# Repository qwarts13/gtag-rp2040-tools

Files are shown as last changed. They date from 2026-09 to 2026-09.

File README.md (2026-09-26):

# G-Tag RP2040 Tools

Два измерительных прибора на одной плате **RP2040-Zero** с экраном от
электронного ценника **G-Tag (SES-imagotag)** 256×128.

| Инструмент | Что делает |
|---|---|
| **Тестер USB-портов** | щуп втыкается в порт ПК: измеряет VBUS, реальные уровни D+ и D−, сопротивление линий, находит замыкания и опознаёт зарядное устройство |
| **Тестер инициализации ПК** | USB-C втыкается в тестируемый компьютер: пассивно, без единого нажатия клавиши, измеряет шкалу загрузки — когда прошивка подняла USB и когда управление забрала операционная система |

Обе функции живут в одной прошивке
[`firmware/GTag_Tester`](firmware/GTag_Tester) и переключаются сами.

**Как выбирается режим.** Прибор постоянно следит за хостом. Перечислил нас
компьютер — по кабелю идут данные, значит включается тестер инициализации.
Хоста нет — значит это зарядка, работает тестер портов. Проверка идёт
непрерывно и не сдаётся: если машина поднимет USB только через несколько
минут, прибор дождётся и начнёт отсчёт с этого момента.

Кнопка **BOOT**: короткое нажатие переворачивает картинку в режиме портов и
перезапускает замер в режиме инициализации, долгое — переключает режим
вручную. Ручной выбор держится до переподключения кабеля, дальше снова
работает автоматика.

---

## Как это выглядит

Экран тестера портов:

```
1 VBUS              4.77V
2 D-                0.02V 25K
3 D+                0.02V 25K
4 GND              USB ТЕСТЕР
```

Экран тестера инициализации:

```
        ТЕСТЕР ИНИЦИАЛИЗАЦИИ ПК
┌──────────────────────────────────┐
│  INIT                YES         │
└──────────────────────────────────┘
┌──────────────────────────────────┐
│  OS BOOT            27.4S        │
└──────────────────────────────────┘
```

Схемы подключения: [распиновка](images/pinout.svg) ·
[щуп с делителем](images/probe.svg) · [подключение экрана](images/lcd.svg).

Живые снимки: [тестер портов на столе](images/photos/running-port.jpg) ·
[замер живого порта](images/photos/measuring-live-port.jpg) ·
[режим инициализации](images/photos/running-init.jpg) ·
[внутренности сборки](images/photos/inside.jpg) ·
[в корпусе](images/photos/case-closed.jpg).

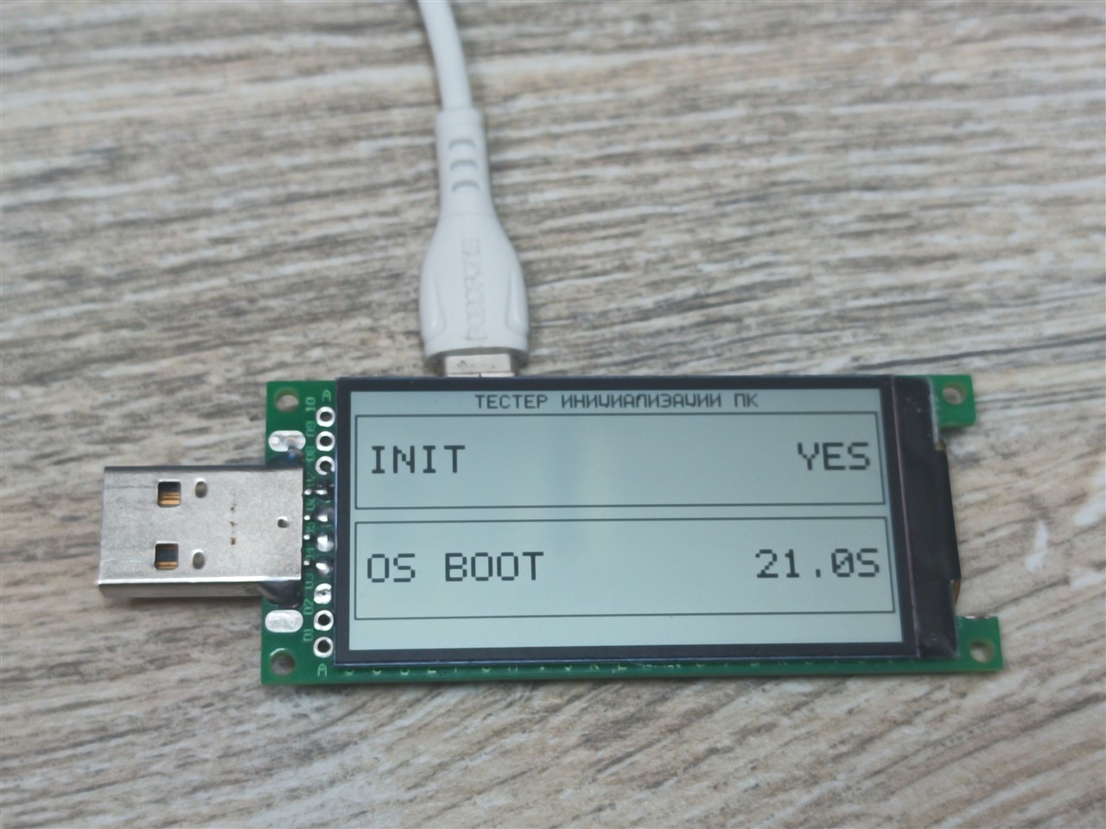
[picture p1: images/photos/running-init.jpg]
Тестер инициализации ПК


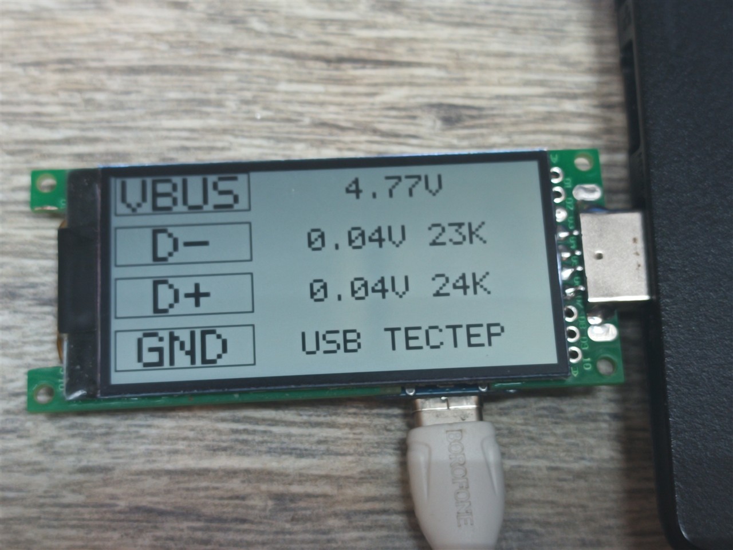
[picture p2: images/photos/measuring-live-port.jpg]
Тестер портов измеряет живой порт


---

## Железо

| Что | Зачем |
|---|---|
| RP2040-Zero | мозг, USB-контроллер и АЦП |
| Экран от ценника G-Tag 256×128 | индикатор, четыре сигнальных провода |
| Плата ценника (остаётся в сборе) | питание экрана и **DisplayCLK 28,8 кГц** |
| USB-A штекер на проводах | измерительный щуп тестера портов |
| Динамик | сигнал о замыкании и о подтверждённой инициализации |

Всё это собрано на **макетной плате 3×7 см**: на ней разместились RP2040-Zero,
обвязка щупа (делитель 100к/100к, резисторы 1к, эталон 10к) и динамик. Экран
вынесен на четырёх проводах, плата ценника остаётся в своём корпусе и даёт
`DisplayCLK`.

### Распиновка RP2040-Zero (USB-C сверху)

```
        левый край                 правый край
        5V        (1)              (23)  GP0
        GND       (2)              (22)  GP1
        3V3       (3)              (21)  GP2
        GP29      (4)              (20)  GP3
        GP28      (5)              (19)  GP4
        GP27      (6)              (18)  GP5
        GP26      (7)              (17)  GP6
        GP15      (8)              (16)  GP7
        GP14      (9)              (15)  GP8
              нижний торец:  GP13(10) GP12(11) GP11(12) GP10(13) GP9(14)
```

### Подключение

| Сигнал | GPIO |
|---|---|
| Экран: RESET / CS / CLK / DIO | GP8 / GP9 / GP10 / GP11 |
| Экран: GND | GND |
| Щуп: VBUS через делитель 100к/100к | GP26 |
| Щуп: D− через 1к | GP27 |
| Щуп: D+ через 1к | GP28 |
| Эталонный резистор 10к на GND | GP29 |
| Динамик | GP7 |

Подробности, включая защиту линий данных и проверку мультиметром перед
первым включением — в [docs/wiring.md](docs/wiring.md).

Как снять экран со штатного ценника и что там перерезать — в
[docs/tag-preparation.md](docs/tag-preparation.md).

## Корпус

Печатный корпус под эту сборку лежит в [hardware/stl](hardware/stl) — три
STL-файла, печать на FDM, стягивается четырьмя винтами. Внутри помещаются
RP2040-Zero, обвязка щупа и динамик; USB-C и кнопка BOOT выведены наружу,
щуп выходит слева.

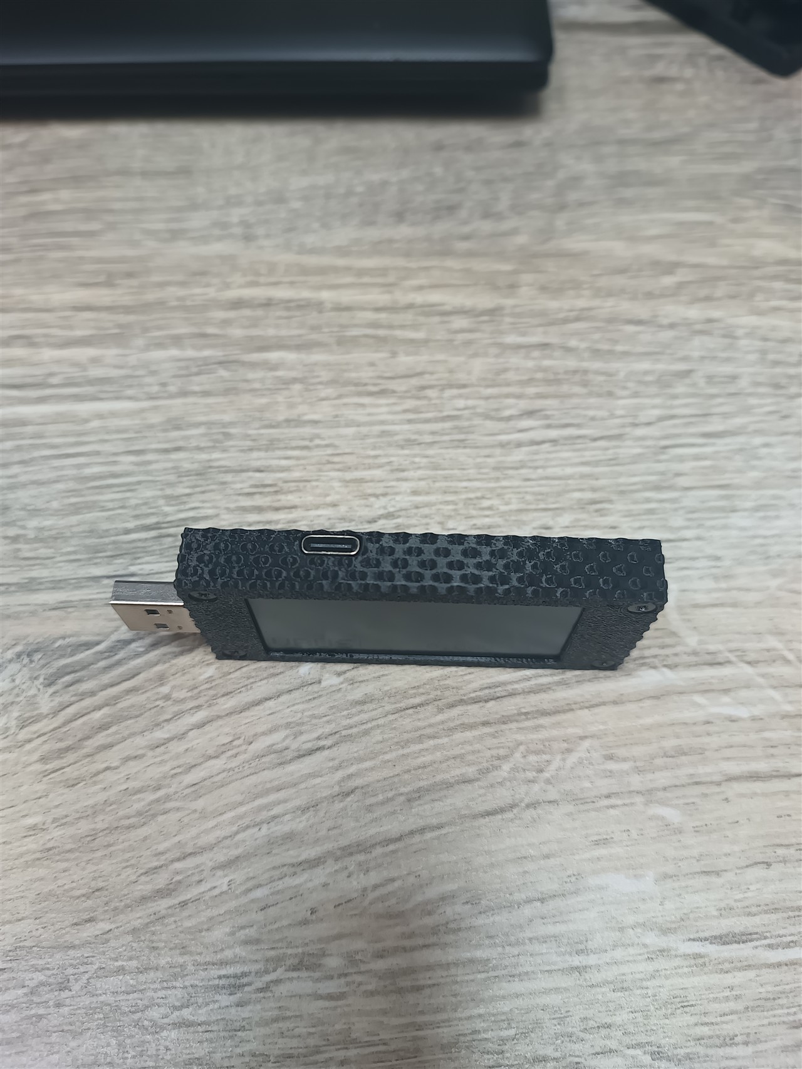
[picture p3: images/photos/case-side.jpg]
Корпус, вид сбоку


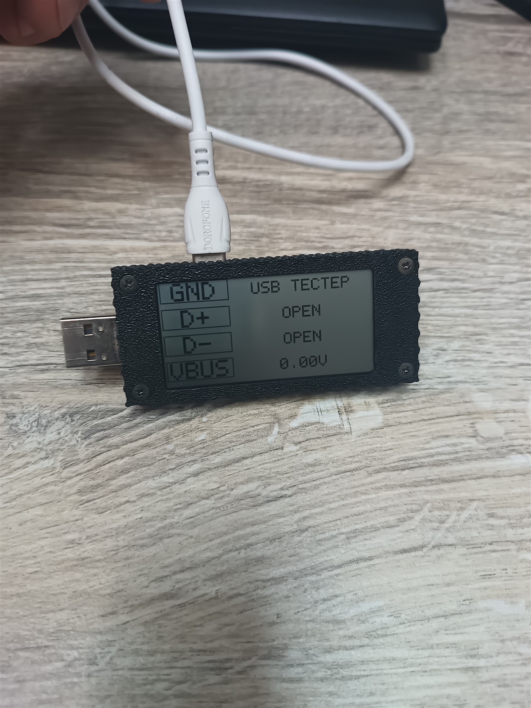
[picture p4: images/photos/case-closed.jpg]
Собранный прибор


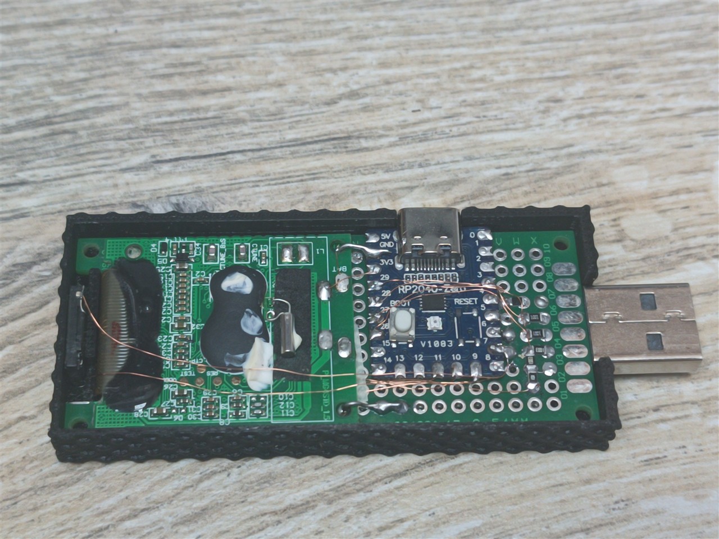
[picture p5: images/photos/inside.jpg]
Сборка изнутри


---

## Быстрая прошивка готовым файлом

Собирать самому не обязательно. Готовый бинарник живёт **только в релизах** —
в дереве репозитория его нет намеренно, чтобы ни у кого случайно не оказалось
старой версии. Прямая ссылка всегда отдаёт последнюю:

```
https://github.com/qwarts13/gtag-rp2040-tools/releases/latest/download/GTag_Tester.uf2
```

Затем:

1. Зажать **BOOT** на плате и подключить USB-C — появится диск `RPI-RP2`.
2. Перетащить на него `GTag_Tester.uf2`.
3. Плата сама перезагрузится и запустится.

Собрано под `Waveshare RP2040 Zero` со стеком Adafruit TinyUSB. Формат UF2
привязан к семейству чипа, а не к конкретной модели платы, поэтому файл
подойдёт любому RP2040.

## Сборка из исходников

Скетч для **Arduino IDE 2.x** с ядром
[Raspberry Pi Pico/RP2040 by Earle Philhower](https://github.com/earlephilhower/arduino-pico).

1. **File → Preferences → Additional boards manager URLs:**
   `https://github.com/earlephilhower/arduino-pico/releases/download/global/package_rp2040_index.json`
2. **Tools → Boards → Boards Manager** → установить *Raspberry Pi Pico/RP2040*.
3. **Tools → Board** → `Waveshare RP2040 Zero`.
4. **Tools → USB Stack → Adafruit TinyUSB.** Это обязательно: тестер
   инициализации представляется HID-клавиатурой, а без TinyUSB сборка
   останавливается с ошибкой «TinyUSB is not selected».
5. Открыть `firmware/GTag_Tester/GTag_Tester.ino`, залить. Первая заливка —
   с зажатой кнопкой BOOT (плата определится как диск `RPI-RP2`).

---

## Тестер USB-портов

Щуп идёт в порт под тестом, питание — от зарядки, вставленной в USB-C.

Для каждой линии измеряется реальное напряжение, классифицируется состояние
сети и оценивается сопротивление до земли:

| Состояние | Что означает |
|---|---|
| `OPEN` | линия ни к чему не подключена |
| `HOST PULL-DOWN` | видны подтяжки хоста 15к — порт живой |
| `DEVICE PULL-UP` | линию держит вверху подключённое устройство |
| `SHORT TO GND` | линию не поднять, она на земле |

КЗ между D+ и D− ищется так: одна линия подтягивается вверх, вторая вниз, и
если они «съезжают» вместе — значит замкнуты. На экране между строками
появляется двусторонняя стрелка, а динамик пищит.

Зарядное устройство опознаётся по подписи BC1.2: у него D+ и D− соединены
накоротко, поэтому обе линии высокие и одинаковые. Это тоже считается
замыканием и тоже озвучивается — тестер не делает скидок на то, что так
задумано производителем.

### Как измеряется сопротивление

Сопротивление считается по внутренней подтяжке RP2040, а её номинал плавает
в диапазоне 40–80к. Поэтому при старте прошивка калибруется по двум известным
резисторам на плате: эталонному 10к на GP29 и нижнему плечу делителя 100к на
GP26. Из двух уравнений находятся сразу оба неизвестных — сопротивление
подтяжки и реальное напряжение её шины.

Проверка на живом примере: 15к, припаянные к линии вместо щупа, показываются
как 16к — с учётом последовательного резистора 1к. Подробности в
[docs/calibration.md](docs/calibration.md).

---

## Тестер инициализации ПК

USB-C идёт в компьютер под тестом, устройство представляется HID-клавиатурой.
Дальше **не нажимается ни одна клавиша** — тестер только слушает то, что хост
делает сам.

| Метка | Событие |
|---|---|
| `INIT` | хост перечислил устройство. Это и есть инициализация порта, и она фиксируется независимо от того, прошивка это или ОС |
| `OS BOOT` | время от инициализации до того, как дала о себе знать ОС: либо сброс шины и повторное перечисление, либо состояние лампочек клавиатуры, которое присылает драйвер |

### Почему без нажатий

Нажатие клавиши даёт ответ только если хост уже обрабатывает клавиатуру:
BIOS, поднявший порт, но не загрузивший драйвер ввода, промолчит. Поэтому
тестер слушает только то, что хост делает сам:

- **перечисление устройства** — присвоение USB-адреса и конфигурация;
- **трафик на шине** — хост опрашивает нас постоянно, пока жив;
- **состояние лампочек** (`SET_REPORT`, выходной отчёт) — Windows и Linux
  присылают его при загрузке драйвера, без единого нажатия;
- **смена протокола boot → report** — признак того, что управление забрала ОС.

Кнопка BOOT: короткое нажатие — перезапуск замера, долгое — переключение
режима прибора.

---

## Что внутри экрана

Протокол LCD восстановлен не на глаз: последовательность команд, формат
9-битных слов и тайминги сверены с записью логического анализатора, снятой с
штатной прошивки ценника в проекте
[**lukdut/gtag-nrf-display**](https://github.com/lukdut/gtag-nrf-display)
(лицензия MIT). Драйвер LCD в этом репозитории — его порт на RP2040.
Инициализация отправляет ровно 4172 слова, кадр — 4100, и это совпадает
байт в байт. Разбор — в [docs/lcd-protocol.md](docs/lcd-protocol.md).

Огромная благодарность автору того проекта: без снятого захвата пришлось бы
разбирать протокол вслепую.

---

## Автор

Евгений Кузьмин ([@Qwarts13](https://github.com/Qwarts13)).

## Лицензия

MIT, см. [LICENSE](LICENSE).

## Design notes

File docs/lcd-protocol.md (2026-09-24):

# Протокол экрана G-Tag

Драйвер не написан на глаз: последовательность команд, формат слов и тайминги
сверены с записью логического анализатора, снятой с **штатной прошивки
ценника** в проекте
[lukdut/gtag-nrf-display](https://github.com/lukdut/gtag-nrf-display), файл
`docs/lcd-protocol-review.md`.

## Интерфейс

От платы к экрану идут **четыре сигнала**:

| Сигнал | GPIO |
|---|---|
| RESET | GP8 |
| CS | GP9 |
| CLK | GP10 |
| DIO | GP11 |

`DisplayCLK` (~28,8 кГц) и питание экрана даёт сама плата ценника. Прошивка
этот сигнал не формирует. `TE` в этой модели не используется.

## Передача слова

Каждое слово — **9 бит**: первый бит признак «команда или данные», затем восемь
бит данных, старшим вперёд.

```
CLK в покое низкий
CS опускается
устанавливается бит D/C
данные выставляются при низком CLK
CLK поднимается — данные защёлкиваются
... и так девять раз
CS поднимается после КАЖДОГО слова
```

Полупериод CLK — около 2 мкс, то есть примерно 250 кГц. Чтобы было понятно,
насколько это «медленно» и надёжно: у записанного оригинала период гулял в
пределах 3,5–4,25 мкс, так что мы укладываемся в тот же коридор.

## Последовательность инициализации

| Этап | Слова | Пауза после |
|---|---|---|
| `11` — выход из сна, затем очистка всех 16 страниц по 256 байт значением `FF` | 4161 | 10 мс |
| `4C 0C 00 00 00` — именно **четыре** байта данных | 5 | 4 мс |
| `4D FF 00 7F` | 4 | 1 мс |
| `4E 60` | 2 | 500 мс |
| **итого** | **4172** | |

## Вывод кадра

```
2A 00 00   — адрес 0
2C         — запись в память
4096 байт  — сам кадр
```

Итого 4100 слов.

## Формат кадра

Кадр — 4096 байт, по биту на пиксель.

```
индекс байта = y * 32 + x / 8
бит          = x % 8
значение 1   = белый
```

Разрешение 256×128.

Счётчик слов — независимая проверка: он не зависит от того, как выглядит
картинка. В нашей реализации он выводит в Serial:

```
init total   779 ms   4172 words  exp 4172 OK
frame        210 ms   4100 words  exp 4100 OK
```

Значит в панель уходит ровно тот же поток слов, что и у штатной прошивки
ценника, вплоть до количества.

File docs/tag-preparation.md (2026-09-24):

# Подготовка платы ценника

Экран, который мы используем, снят со штатного электронного ценника G-Tag.
Штатная плата ценника при этом **остаётся в сборке и работает**: именно она
питает LCD и выдаёт тактирование `DisplayCLK / S1` на 28,8 кГц. Прошивка
RP2040 этот сигнал не формирует.

Наша задача — перерезать четыре дорожки, отделив линии управления LCD от
штатного контроллера ценника, и вывести эти четыре сигнала наружу.

> **Не путать:** `CLK` в таблице ниже — это тактовая линия передачи данных,
> отдельный провод. `DisplayCLK / S1` — другой сигнал, его трогать не нужно,
> он так и остаётся на плате ценника.

## Порядок работы

### 1. Открыть корпус

Поддеть защёлки отвёрткой и вынуть сборку платы с экраном.

### 2. Отклеить плату от экрана

Плата держится на двустороннем скотче. Аккуратно поддеть край и прикладывать
небольшое постоянное усилие — скотч постепенно отпустит. Не тянуть резко и не
натягивать шлейф.

### 3. Перерезать четыре дорожки

Очистить обратную сторону платы от остатков скотча (механически или спиртом)
и дать высохнуть. Перерезать дорожки **в четырёх местах**, отмеченных красными
штрихами на фото:

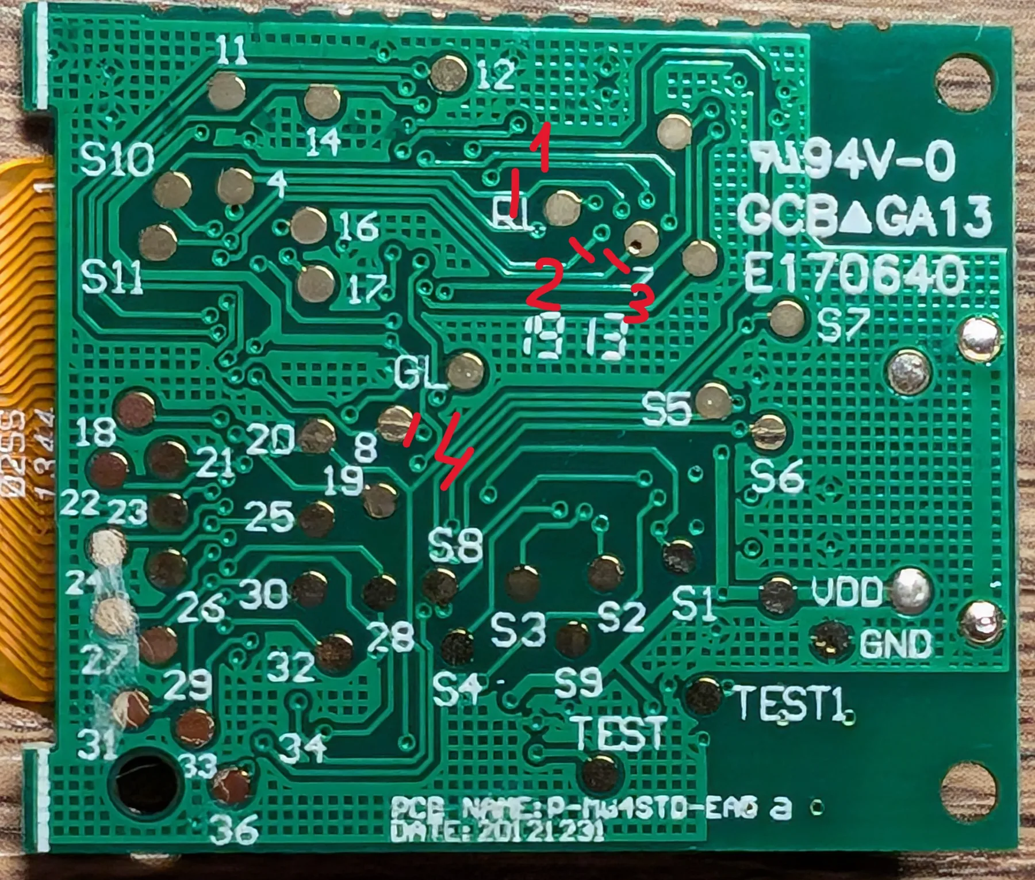
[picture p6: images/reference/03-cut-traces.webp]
Четыре места разрезания дорожек на обратной стороне платы


После работы обязательно проверить мультиметром, что каждый разрез
действительно разрывает нужную дорожку, а соседние остались целыми.

### 4. Подготовить точки пайки

Найти четыре точки **DIO, CLK, CS и RESET**, залудить их:

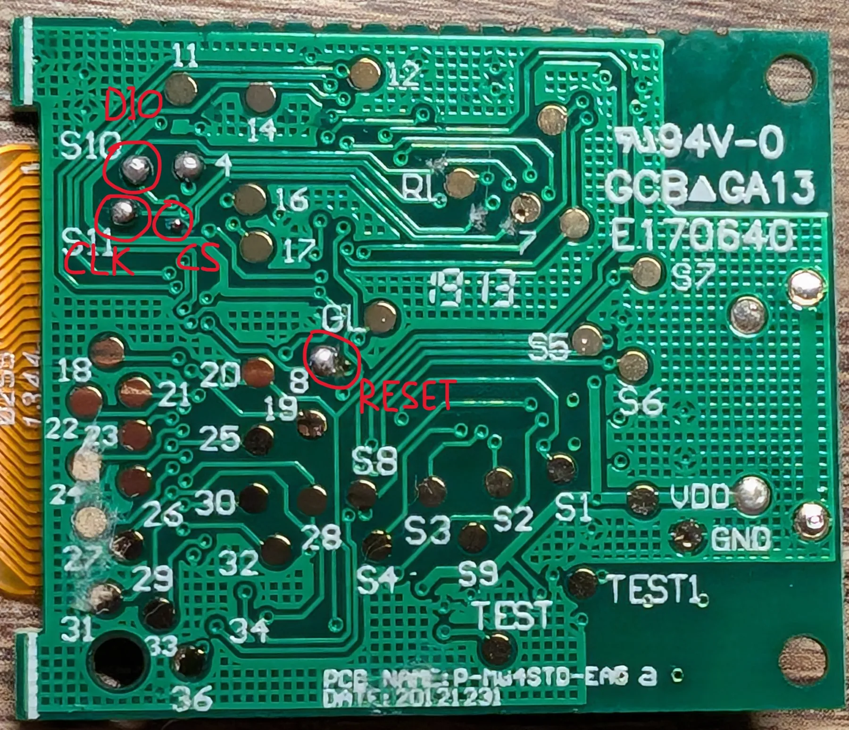
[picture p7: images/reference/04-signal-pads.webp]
Подписанные точки пайки DIO, CLK, CS и RESET


### 5. Припаять провода

Уложить четыре сигнальных провода вдоль поверхности платы, чтобы они не
торчали перпендикулярно. Питание вывести двумя проводами: плюс и минус.

## Куда что идёт на RP2040

| Провод от экрана | GPIO на RP2040-Zero | Пин на плате |
|---|---|---|
| RESET | GP8 | 15 |
| CS | GP9 | 14 |
| CLK | GP10 | 13 |
| DIO | GP11 | 12 |
| GND | GND | 2 |

Плюс обязательная общая земля между RP2040 и платой ценника.

## Источник

Фотографии и порядок операций взяты из проекта
[lukdut/gtag-nrf-display](https://github.com/lukdut/gtag-nrf-display), раздел
`docs/display-preparation.md` (лицензия MIT). Там же описан вариант разводки,
когда переходное отверстие находится рядом с контрольной площадкой, а не на
ней — на некоторых ревизиях платы разрез делается иначе.

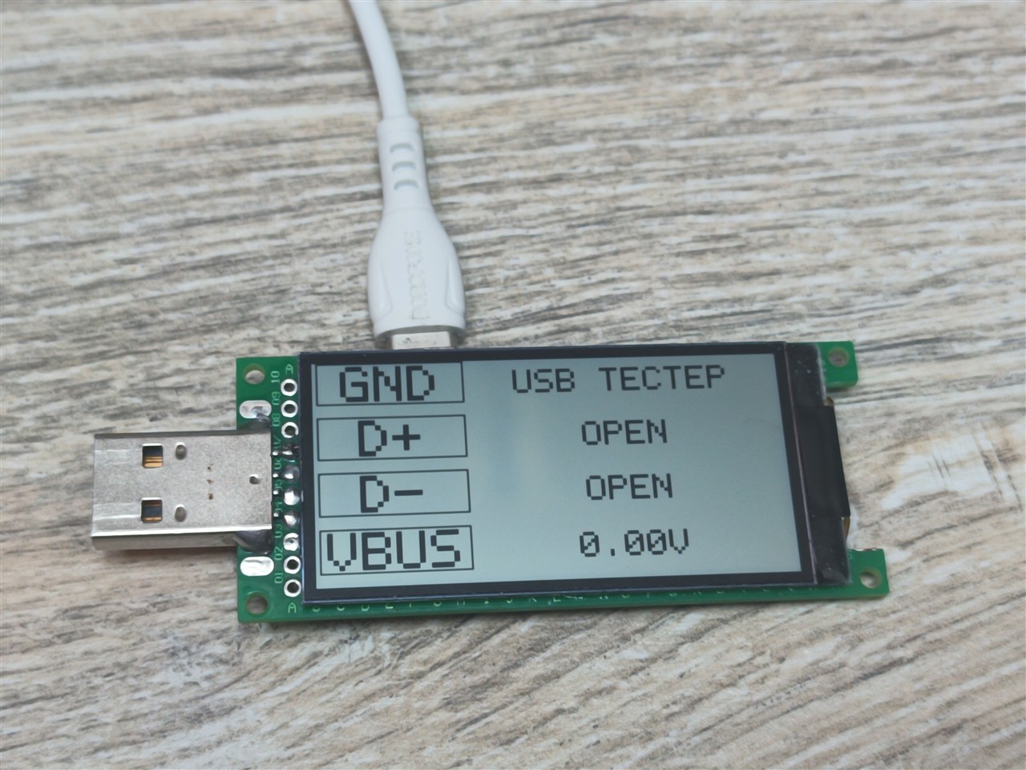
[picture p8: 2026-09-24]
images/photos/running-port.jpg

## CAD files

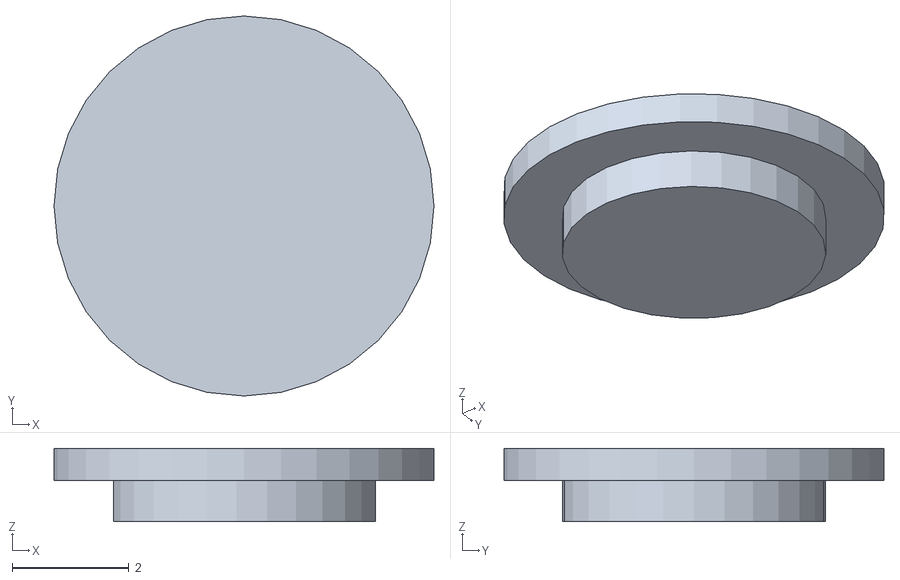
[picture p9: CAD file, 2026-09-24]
hardware/stl/USB_Tester_3.stl
6.50 x 6.50 x 1.25

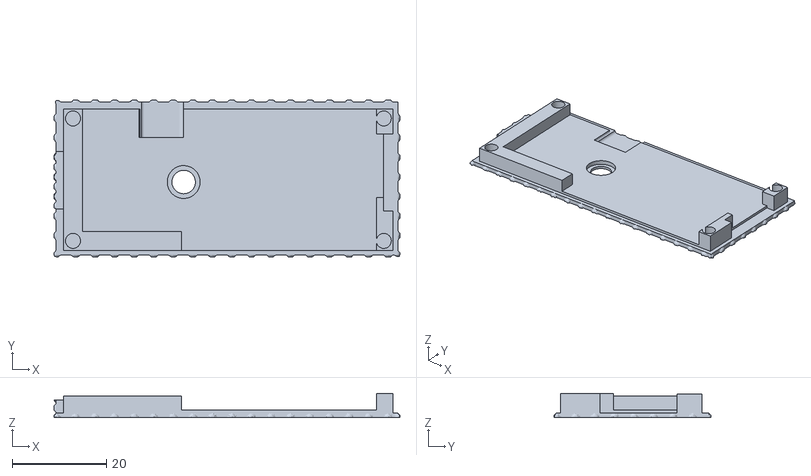
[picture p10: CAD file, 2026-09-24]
hardware/stl/USB_Tester_2.stl
73.5 x 33.4 x 5.20

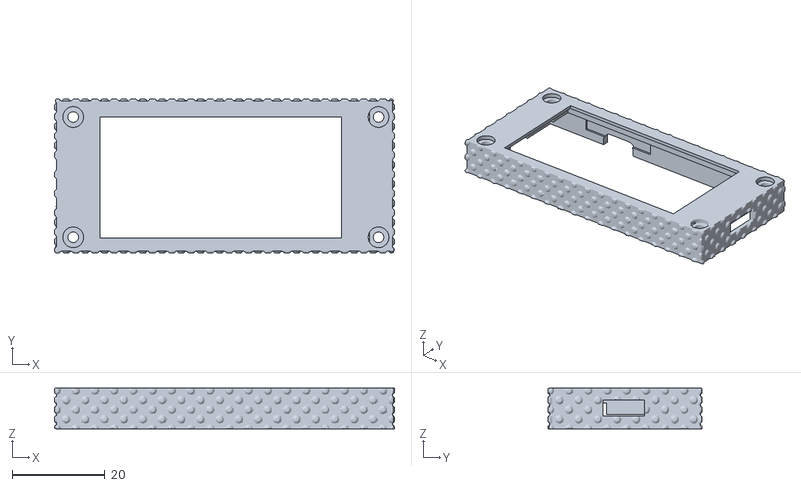
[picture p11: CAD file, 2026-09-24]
hardware/stl/USB_Tester_1.stl
73.5 x 33.4 x 8.80

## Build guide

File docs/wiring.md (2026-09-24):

# Подключение

## Состав устройства

1. **RP2040-Zero** — мозг, USB-контроллер, АЦП.
2. **Экран от ценника G-Tag** 256×128 — индикатор.
3. **Плата ценника** — остаётся в сборе. Именно она питает экран и выдаёт
   `DisplayCLK` 28,8 кГц. Без неё картинки не будет.
4. **USB-A штекер на проводах** — измерительный щуп тестера портов.
5. **Динамик** — сигнал о замыкании и о подтверждённой инициализации.

Родной USB-C платы не трогаем: он остаётся для питания и для режима
HID-клавиатуры.

## Распиновка RP2040-Zero

Нумерация — позиции площадок, при **USB-C сверху**. На шелкографии платы
подписаны имена GPIO, так что ориентируйся по ним.

```
        левый край                 правый край
        5V        (1)              (23)  GP0
        GND       (2)              (22)  GP1
        3V3       (3)              (21)  GP2
        GP29      (4)              (20)  GP3
        GP28      (5)              (19)  GP4
        GP27      (6)              (18)  GP5
        GP26      (7)              (17)  GP6
        GP15      (8)              (16)  GP7
        GP14      (9)              (15)  GP8
              нижний торец:  GP13(10) GP12(11) GP11(12) GP10(13) GP9(14)

        пин 2 = GND, пин 3 = 3V3, пин 1 = 5V, пин 23 = VSYS (= VUSB)
```

## Экран от ценника

| Сигнал экрана | GPIO | Пин на плате |
|---|---|---|
| RESET | GP8 | 15 |
| CS | GP9 | 14 |
| CLK | GP10 | 13 |
| DIO | GP11 | 12 |
| GND | GND | 2 |

**Не подключаем:**

- `XCLK` / `DisplayCLK` — его выдаёт штатная плата ценника. Прошивка этот
  сигнал не формирует.
- `TE` — в этом экране не используется вообще.

Плата ценника обязана остаться подключённой: она питает LCD и даёт
`DisplayCLK`. В проекте
[lukdut/gtag-nrf-display](https://github.com/lukdut/gtag-nrf-display) для этого
на обратной стороне платы ценника перерезают четыре дорожки, отделяя линии
управления LCD от штатного контроллера, и выводят их наружу — раздел
`display-preparation` в их репозитории.

Провода экрана держать короткими, общий GND — как можно короче.

## Щуп

Берём USB-A штекер и четыре провода. Нумерация контактов USB-A стандартная:
1 = VBUS, 2 = D−, 3 = D+, 4 = GND.

| USB-A | Линия | Куда на плате | Через что |
|---|---|---|---|
| 1 | VBUS | GP26 (пин 7) | делитель 100к + 100к |
| 2 | D− | GP27 (пин 6) | резистор 1к |
| 3 | D+ | GP28 (пин 5) | резистор 1к |
| 4 | GND | GND (пин 2) | напрямую |

### Делитель VBUS

Здесь чаще всего путаются, поэтому подробно. Нужны **два одинаковых резистора
по 100к**, включённых последовательно, а провод на GP26 берётся **из точки
между ними**:

```
   USB-A VBUS (контакт 1) ────[ 100к ]
                                   │
                                   ├──── GP26 (пин 7)   ← средняя точка
                                   │
                              [ 100к ]
                                   │
   USB-A GND (контакт 4) ──────────┴──── GND платы
```

Резисторы равны, поэтому 5 В делятся ровно пополам: на GP26 приходит 2,5 В.
Это безопасно для АЦП.

**Главное:** провод на GP26 идёт в середину цепочки. Если припаять его к
краю — к самому VBUS или к земле — делить будет нечего, и напряжение мерить
будет нечем.

### Почему именно АЦП-пины

У RP2040 аналоговый вход есть **только** на GP26…GP29. На обычных цифровых
пинах `analogRead` вернёт ноль, и тестер не сможет измерить ни напряжение,
ни сопротивление. Поэтому щуп обязан стоять именно на этих четырёх ногах.

Зато видно не «0 или 1», а реальное напряжение, и состояние линии
определяется однозначно:

```
0 В на обоих          — устройство не подключено
~3,0–3,3 В на D+      — подключено full-speed устройство
~3,0–3,3 В на D−      — подключено low-speed устройство
одинаково на обоих    — замыкание D+ на D−
~0 В при подтяжке     — КЗ на GND
```

### Защита

Между линиями данных и GPIO **обязателен резистор 1к**, а лучше ещё и
диодная сборка.

В режиме поиска неисправностей на линии может оказаться 5 В, а GPIO RP2040
больше 3,6 В не терпят. Резистор ограничивает ток, сборка **BAT54S** зажимает
напряжение на безопасном уровне.

BAT54S (SOT-23), цоколёвка: вывод 1 — анод нижнего диода, вывод 2 — катод
верхнего, вывод 3 — середина. Подключение на каждую линию данных:

```
   USB-A D+ ──[ 1к ]──┬─── GP28
                      │
                   ┌──┴──┐
                   │  3  │   BAT54S
                  1│     │2
                   │     │
                  GND   3V3
```

Нужно **две** такие сборки — по одной на D+ и D−.

Если BAT54S не найти, подойдут четыре обычных диода Шоттки, по два на линию:
один от линии на 3V3 (катодом к 3V3), второй с GND на линию (катодом к
линии). Подойдут 1N5817, 1N5819, BAT85.

**Важно:** нужен именно **Шоттки**. Обычный кремниевый диод откроется только
при 3,3 + 0,7 = 4,0 В, а это уже выше предела для GPIO.

## Эталонный резистор

```
   GP29 (пин 4) ──[ 10к ]── GND
```

Сопротивления на линиях данных считаются по внутренней подтяжке RP2040, а её
номинал плавает в диапазоне 40–80к. Этот резистор служит эталоном: при старте
прошивка измеряет через него свою подтяжку и дальше считает точно. Без него
числа будут приблизительными.

## Динамик

| Тип динамика | Подключение | Настройка |
|---|---|---|
| Пассивный пьезо | GP7 → пьезо → GND | `BUZZER_ACTIVE 0` |
| Активный буззер | плюс на GP7, минус на GND | `BUZZER_ACTIVE 1` |
| Магнитный (с катушкой) | через резистор ~100 Ом, диод параллельно | `BUZZER_ACTIVE 0` |

## Питание

Питаем устройство **от родного USB-C**.

Если запитать тестер портов от порта компьютера, прибор увидит перечисление
USB, примет это за данные и запустится в режиме тестера инициализации. Это не
ошибка — по шине действительно идут данные. Лечится зарядкой либо долгим
нажатием кнопки.

**Внимание по RP2040-Zero:** пин 23 (VSYS) напрямую соединён с VUSB, то есть
с VBUS родного разъёма. Нельзя одновременно втыкать USB-C и подавать 5 В со
щупа на пин 23 — получится два источника на одной цепи.

## Проверка мультиметром перед первым включением

1. GND платы ↔ GND USB-A: звонятся, ~0 Ом
2. USB-A VBUS ↔ GP26: ~200к
3. GP26 ↔ GND: ~100к
4. D− ↔ GP27: ~1к
5. D+ ↔ GP28: ~1к
6. GP29 ↔ GND: ~10к
7. VBUS ↔ GND: низкого сопротивления быть НЕ должно
8. D+ ↔ D−: низкого сопротивления быть НЕ должно

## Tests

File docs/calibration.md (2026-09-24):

# Калибровка измерений

## Задача

Тестер показывает не только напряжение, но и сопротивление линий данных.
Измерять его напрямую нечем — в схеме нет ни образцового резистора на линии,
ни источника тока. Единственный доступный инструмент — **внутренняя подтяжка
RP2040**: если подать её на измеряемую линию, по установившемуся напряжению
можно восстановить внешнее сопротивление.

```
   R = Rpullup * V / (Vcc - V)
```

Беда в том, что `Rpullup` у RP2040 не нормирован точно: паспорт даёт разброс
примерно 40–80к, и у каждой платы он свой. Плюс АЦП не идеален. Если взять
паспортные 50к и ровно 3,3 В, ошибка выходит в разы.

## Решение: два известных резистора

На плате уже есть **два резистора с известным номиналом**, и оба висят на
АЦП-пинах:

| Резистор | Пин | Номинал |
|---|---|---|
| эталонный | GP29 | 10к на землю |
| нижнее плечо делителя VBUS | GP26 | 100к на землю |

Это даёт **две точки** и, соответственно, два уравнения — значит можно найти
сразу **два** неизвестных: сопротивление подтяжки и реальное напряжение её
шины.

Измеряем напряжение на каждом из них при включённой подтяжке:

```
v10  = Vcc * 10  / (Rpu + 10)
v100 = Vcc * 100 / (Rpu + 100)
```

Делим одно на другое и решаем систему:

```
Rpu = 54900 Ом
Vcc = 3.95 В
```

Полученные значения подставляются в формулу сопротивления. Прошивка делает
это сама при старте и печатает результат в Serial:

```
cal: Rpu=59682 ohm  Vcc=4.053 V  (v10=0.596 v1=2.950 vbus=4.78)
```

## Про получившееся «Vcc = 4 В»

Шина подтяжки питается от 3,3 В, там физически не может быть четырёх вольт.
Это не ошибка расчёта, а следствие того, что АЦП и внутренняя подтяжка не
подчиняются простой модели «резистор к питанию»: подгонка выкручивает
параметр, чтобы попасть в две известные точки.

Практический смысл в том, что **в диапазоне между этими двумя точками
результат получается верным**: модель, подогнанная по 10к и 100к, честно
считает и промежуточные номиналы вокруг 15–25к, то есть именно тот диапазон,
который встречается на линиях USB.

## Проверка

Живой тест: вместо щупа на линию D− припаивается резистор **15к**, и тестер
показывает **16к** — ровно 15к плюс последовательный 1к в линии.

На другом порту тестер показал 24к вместо ожидаемых 16к. Ошибки здесь нет:
у того порта действительно другие подтяжки.

## Когда калиброваться

Лучше всего — при **воткнутом щупе в живой порт** или **вообще без щупа**.
Прошивка различает три случая по состоянию линии VBUS:

| `vbus` | Ситуация | Что видит GP26 |
|---|---|---|
| > 0,3 В | щуп в живом порту | верхнее плечо сидит на VBUS, ветка учитывается |
| < 0,03 В | щуп в мёртвом порту | оба плеча грузят пин |
| между | щуп не воткнут | только нижнее плечо 100к |

Во всех трёх случаях система решается корректно.

## Точность

| Что | Насколько точно |
|---|---|
| Напряжение VBUS | делитель работает по соотношению, оно верное при любых одинаковых резисторах |
| Классификация линий (пусто / хост / устройство / КЗ) | надёжна, пороги разнесены широко |
| Абсолютное сопротивление | точное в диапазоне 10к–100к при откалиброванной подтяжке |
| Сопротивление вне этого диапазона | оценочное |

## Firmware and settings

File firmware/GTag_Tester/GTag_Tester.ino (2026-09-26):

// ============================================================
//  GTag_Tester - one board, two instruments
//
//  1. USB PORT TESTER - probe in the port under test, measures VBUS, D+ and
//     D- voltages, line resistance, shorts, charger signatures. Powered from
//     a charger (no data on the USB-C connector).
//
//  2. PC INIT TESTER - the USB-C goes into the machine under test. The board
//     enumerates as a USB HID keyboard and, without pressing anything,
//     watches what the host does by itself: enumeration, keyboard LED state,
//     protocol handover, re-enumeration.
//
//  Mode selection:
//    - at power up the board waits a few seconds. If the host enumerated us
//      there is data on the connector, so it starts the init tester,
//      otherwise it assumes a charger and starts the port tester.
//    - BOOTSEL short press: flip the picture (port tester) / restart the
//      measurement (init tester).
//    - BOOTSEL long press: switch mode manually.
//
//  IMPORTANT: Tools -> USB Stack must be set to "Adafruit TinyUSB".
//
//  Board: RP2040-Zero, core: Raspberry Pi Pico/RP2040 (Earle Philhower)
//    LCD    -> GP8..GP11, plus the tag board for DisplayCLK
//    Buzzer -> GP7, optional
//    Probe  -> GP26 VBUS (100k/100k), GP27 D-, GP28 D+, GP29 10k reference
// ============================================================

#include <Arduino.h>
#include "Adafruit_TinyUSB.h"
#include "gtag_lcd.h"

// ---------------- config ----------------
#define PIN_BUZZER       7
#define BUZZER_ACTIVE    0            // 0 = passive piezo (tone), 1 = active buzzer
static constexpr uint16_t BEEP_HZ = 2200;

#define PIN_VBUS    26   // ADC0, through 100k/100k divider
#define PIN_DPLUS   28   // ADC2
#define PIN_DMINUS  27   // ADC1
#define REF_PIN     29   // ADC3, 10k to GND
#define REF_OHM     10000
#define PULLUP_NOMINAL 50000.0f

static constexpr float    VCC      = 3.3f;
static constexpr bool     INK      = false;   // black ink on white paper
static constexpr float    SHORT_V  = 0.5f;    // cross-line coupling threshold
static constexpr uint32_t DRAW_MS  = 400;
static constexpr uint32_t LOG_MS   = 1500;
static constexpr uint32_t PRESS_LONG_MS = 700;  // longer than this = mode switch

static float g_pullup = PULLUP_NOMINAL;   // refined by calibration
static float g_vcc    = VCC;

// ---------------- measurement types ----------------
// Must sit before the first function: the Arduino builder inserts the
// generated prototypes just ahead of the first function body.
enum LineState : uint8_t { LN_UNKNOWN, LN_OPEN, LN_HOST_PD, LN_DEV_UP, LN_SHORT_GND };

struct Reading {
  float     vbus;
  float     vP, vN;
  float     rP, rN;
  float     rShort;
  LineState sP, sN;
  bool      shortPN;
  uint16_t  actP, actN;
};

enum Mode : uint8_t { MODE_PORT, MODE_INIT };

// ---------------- HID ----------------
static uint8_t const desc_hid_report[] = { TUD_HID_REPORT_DESC_KEYBOARD() };
Adafruit_USBD_HID usb_hid;

static void hid_report_callback(uint8_t report_id, hid_report_type_t report_type,
                                uint8_t const *buffer, uint16_t bufsize);

static volatile uint32_t led_reports = 0;
static volatile uint8_t  led_state   = 0;

// The host's keyboard LED state arrives here. No key press is involved: the
// OS and the Linux kernel send this on their own when the driver loads.
static void hid_report_callback(uint8_t report_id, hid_report_type_t report_type,
                                uint8_t const *buffer, uint16_t bufsize) {
  (void)report_id;
  if (report_type != HID_REPORT_TYPE_OUTPUT || bufsize < 1) return;
  led_state = buffer[0];
  ++led_reports;
}

// ---------------- buzzer ----------------
static void buzzer_set(bool on) {
#if BUZZER_ACTIVE
  digitalWrite(PIN_BUZZER, on ? HIGH : LOW);
#else
  if (on) tone(PIN_BUZZER, BEEP_HZ);
  else    noTone(PIN_BUZZER);
#endif
}

static void buzzer_beep(int times, uint16_t ms) {
  for (int i = 0; i < times; ++i) {
    buzzer_set(true);  delay(ms);
    buzzer_set(false); delay(ms);
  }
}

static void beep_joy() {
#if BUZZER_ACTIVE
  buzzer_set(true); delay(300); buzzer_set(false);
#else
  tone(PIN_BUZZER, 1600); delay(120); noTone(PIN_BUZZER); delay(60);
  tone(PIN_BUZZER, 2400); delay(220); noTone(PIN_BUZZER);
#endif
}

static void buzzer_alarm(bool alarm) {
  static uint32_t last = 0;
  static bool phase = false;
  if (!alarm) {
    if (phase) { buzzer_set(false); phase = false; }
    return;
  }
  const uint32_t now = millis();
  if ((uint32_t)(now - last) >= 120) {
    last = now;
    phase = !phase;
    buzzer_set(phase);
  }
}

// ============================================================
//  Port tester: measurement
// ============================================================
static float adc_volts(uint8_t pin) {
  uint32_t acc = 0;
  for (int i = 0; i < 8; ++i) acc += (uint32_t)analogRead(pin);
  return (acc / 8.0f) * VCC / 4096.0f;
}

static uint16_t count_edges(uint8_t pin, uint32_t us) {
  gpio_set_function(pin, GPIO_FUNC_SIO);
  gpio_set_dir(pin, GPIO_IN);
  gpio_set_input_enabled(pin, true);

  const uint32_t t0 = micros();
  uint16_t edges = 0;
  int last = gpio_get(pin) ? 1 : 0;
  while ((uint32_t)(micros() - t0) < us) {
    const int v = gpio_get(pin) ? 1 : 0;
    if (v != last) { ++edges; last = v; }
  }

  gpio_set_input_enabled(pin, false);
  gpio_set_function(pin, GPIO_FUNC_NULL);
  return edges;
}

static float r_to_gnd(float v) {
  if (v >= VCC - 0.15f) return -1.0f;
  if (v <= 0.02f)       return 0.0f;
  return g_pullup * v / (g_vcc - v);
}

static float r_between(float v) {
  if (v < 0.1f) return -1.0f;
  const float r = g_pullup * (g_vcc / v - 2.0f);
  return (r < 0.0f) ? 0.0f : r;
}

// The pull-up test decides the state; a line that collapses under a pull-down
// was never really held high.
static LineState classify(float base_v, float pullup_v, float pulldown_v) {
  if (base_v >= 2.5f) {
    return (pulldown_v >= 2.0f) ? LN_DEV_UP : LN_OPEN;
  }
  if (pullup_v >= VCC - 0.3f) return LN_OPEN;
  if (pullup_v >= 0.35f)      return LN_HOST_PD;
  return LN_SHORT_GND;
}

static Reading measure_port() {
  Reading r{};

  gpio_set_pulls(PIN_VBUS, false, false);
  r.vbus = adc_volts(PIN_VBUS) * 2.0f;           // undo the divider

  gpio_set_pulls(PIN_DPLUS, false, false);
  gpio_set_pulls(PIN_DMINUS, false, false);
  delayMicroseconds(300);
  r.vP = adc_volts(PIN_DPLUS);
  r.vN = adc_volts(PIN_DMINUS);

  gpio_set_pulls(PIN_DPLUS, true, false);        // raise D+, hold D- down
  gpio_set_pulls(PIN_DMINUS, false, true);
  delayMicroseconds(300);
  const float uP = adc_volts(PIN_DPLUS);
  const float nUp = adc_volts(PIN_DMINUS);

  gpio_set_pulls(PIN_DPLUS, false, true);        // raise D-, hold D+ down
  gpio_set_pulls(PIN_DMINUS, true, false);
  delayMicroseconds(300);
  const float uN = adc_volts(PIN_DMINUS);
  const float pUp = adc_volts(PIN_DPLUS);

  gpio_set_pulls(PIN_DPLUS, false, false);
  gpio_set_pulls(PIN_DMINUS, false, false);

  // Smoothing keeps the display from flickering, which matters most when the
  // probe is unplugged and the lines are floating.
  static bool  have = false;
  static float sP = 0, sN = 0, sUp = 0, sUn = 0, sBus = 0, sPdn = 0, sNdn = 0;
  if (!have) {
    sP = r.vP; sN = r.vN; sUp = uP; sUn = uN; sBus = r.vbus;
    sPdn = pUp; sNdn = nUp;
    have = true;
  } else {
    const float a = 0.7f;
    sP   = sP   * a + r.vP  * (1.0f - a);
    sN   = sN   * a + r.vN  * (1.0f - a);
    sUp  = sUp  * a + uP    * (1.0f - a);
    sUn  = sUn  * a + uN    * (1.0f - a);
    sBus = sBus * a + r.vbus * (1.0f - a);
    sPdn = sPdn * a + pUp   * (1.0f - a);
    sNdn = sNdn * a + nUp   * (1.0f - a);
  }
  r.vP = sP; r.vN = sN; r.vbus = sBus;
  r.sP = classify(sP, sUp, sPdn);
  r.sN = classify(sN, sUn, sNdn);
  r.rP = r_to_gnd(sUp);
  r.rN = r_to_gnd(sUn);

  const float coupling = (nUp > pUp) ? nUp : pUp;
  r.shortPN = coupling > SHORT_V;
  r.rShort = r.shortPN ? r_between(coupling) : -1.0f;

  r.actP = count_edges(PIN_DPLUS, 5000);
  r.actN = count_edges(PIN_DMINUS, 5000);
  return r;
}

// Two known resistors let us solve for the pull-up value and the effective
// pull-up rail at once: the 10k reference on GP29 and the 100k lower divider
// leg on GP26.
static void calibrate() {
#if REF_OHM > 0
  analogRead(REF_PIN);
  analogRead(PIN_VBUS);

  gpio_set_pulls(REF_PIN, true, false);
  delayMicroseconds(500);
  const float v10 = adc_volts(REF_PIN);
  gpio_set_pulls(REF_PIN, false, false);

  gpio_set_pulls(PIN_VBUS, false, false);
  delayMicroseconds(500);
  const float v0 = adc_volts(PIN_VBUS);

  gpio_set_pulls(PIN_VBUS, true, false);
  delayMicroseconds(500);
  const float v1 = adc_volts(PIN_VBUS);
  gpio_set_pulls(PIN_VBUS, false, false);

  const float vbus = v0 * 2.0f;

  if (v10 > 0.05f) {
    float vcc = g_vcc;
    if (v0 > 0.3f) {
      const float den = 10.0f * v10 - 2.0f * v1 + vbus;   // live VBUS branch
      if (den > 0.1f) vcc = v10 * (8.0f * v1 + vbus) / den;
    } else if (v0 < 0.03f) {
      const float den = 5.0f * v10 - v1;                  // VBUS grounded
      if (den > 0.1f) vcc = 4.0f * v1 * v10 / den;
    } else {
      const float den = 10.0f * v10 - v1;                 // probe unplugged
      if (den > 0.1f) vcc = 9.0f * v1 * v10 / den;
    }
    if (vcc > 2.5f && vcc < 4.6f) {
      const float rpu = (vcc - v10) * (float)REF_OHM / v10;
      if (rpu > 8000.0f && rpu < 200000.0f) g_pullup = rpu;
      g_vcc = vcc;
    }
  }

  Serial.printf("cal: Rpu=%.0f ohm  Vcc=%.3f V  (v10=%.3f v1=%.3f vbus=%.2f)\n",
                g_pullup, g_vcc, v10, v1, vbus);
#else
  (void)REF_PIN;
  Serial.printf("pull-up assumed: %.0f ohm\n", g_pullup);
#endif
}

static const char *state_name(LineState s) {
  switch (s) {
    case LN_OPEN:      return "OPEN";
    case LN_HOST_PD:   return "HOST PULL-DOWN";
    case LN_DEV_UP:    return "DEVICE PULL-UP";
    case LN_SHORT_GND: return "SHORT TO GND";
    default:           return "UNKNOWN";
  }
}

static void fmt_ohm(char *buf, size_t n, float r) {
  if (r < 0.0f || r >= 1000000.0f) snprintf(buf, n, "OPEN");
  else if (r < 1000.0f)            snprintf(buf, n, "%.0f", r);
  else                             snprintf(buf, n, "%.0fK", r / 1000.0f);
}

static void verdict_text(const Reading &r, char *l1, size_t n1, char *l2, size_t n2) {
  l1[0] = l2[0] = 0;
  if (r.vbus < 1.0f) {
    snprintf(l1, n1, "НЕТ ПИТАНИЯ НА VBUS");
    snprintf(l2, n2, "ПРОВЕРЬ КАБЕЛЬ И ПОРТ");
  } else if (r.shortPN) {
    snprintf(l1, n1, "ЗАМЫКАНИЕ D+ И D-");
    snprintf(l2, n2, "ПРОВЕРЬ ПОРТ И КАБЕЛЬ");
  } else if (r.sP == LN_DEV_UP) {
    snprintf(l1, n1, "УСТРОЙСТВО ПОДКЛЮЧЕНО");
    snprintf(l2, n2, "СКОРОСТЬ ВЫСОКАЯ");
  } else if (r.sN == LN_DEV_UP) {
    snprintf(l1, n1, "УСТРОЙСТВО ПОДКЛЮЧЕНО");
    snprintf(l2, n2, "СКОРОСТЬ НИЗКАЯ");
  } else if (r.sP == LN_HOST_PD || r.sN == LN_HOST_PD) {
    snprintf(l1, n1, "ПОРТ ИСПРАВЕН");
    snprintf(l2, n2, "УСТРОЙСТВ НЕ НАЙДЕНО");
  } else if (r.sP == LN_OPEN && r.sN == LN_OPEN) {
    snprintf(l1, n1, "ЛИНИИ ДАННЫХ ОТКРЫТЫ");
    snprintf(l2, n2, "ПОРТ ПУСТ ИЛИ МЕРТВ");
  } else {
    snprintf(l1, n1, "ПРОВЕРЬ ЛИНИИ");
    snprintf(l2, n2, "СМОТРИ СОСТОЯНИЕ");
  }
}

// Both lines held high at once is not a valid USB state for a device: it
// happens when the two lines are tied together, which a charger does on
// purpose and a faulty port does by accident.
static bool both_lines_high(const Reading &r) {
  return r.sP == LN_DEV_UP && r.sN == LN_DEV_UP;
}

static bool looks_like_rail_short(const Reading &r) {
  return both_lines_high(r) && r.vP >= 3.0f && r.vN >= 3.0f;
}

static void print_reading(const Reading &r) {
  char rbP[10], rbN[10], rbS[10], l1[28], l2[28];
  fmt_ohm(rbP, sizeof(rbP), r.rP);
  fmt_ohm(rbN, sizeof(rbN), r.rN);
  fmt_ohm(rbS, sizeof(rbS), r.rShort);
  verdict_text(r, l1, sizeof(l1), l2, sizeof(l2));
  Serial.printf("VBUS %.2f V | D+ %.2f V (%s, R %s) | D- %.2f V (%s, R %s)\n",
                r.vbus, r.vP, state_name(r.sP), rbP, r.vN, state_name(r.sN), rbN);
  Serial.printf("short D+/D-: %s (R %s) | activity D+ %u  D- %u\n",
                r.shortPN ? "YES" : "no", rbS, r.actP, r.actN);
  Serial.printf("verdict: %s / %s\n", l1, l2);
  if (looks_like_rail_short(r))
    Serial.println("WARNING: both lines at the rail - suspect D+/D- shorted to +5V");
  else if (both_lines_high(r))
    Serial.println("short: D+ and D- are tied together (charger signature or faulty port)");
}

// ---------------- port tester screen ----------------
static void render_port(const Reading &r) {
  char rbP[10], rbN[10];
  fmt_ohm(rbP, sizeof(rbP), r.rP);
  fmt_ohm(rbN, sizeof(rbN), r.rN);

  memset(glcd_fb, 0xFF, sizeof(glcd_fb));

  static const char *const label[4] = {"VBUS", "D-", "D+", "GND"};
  char val[4][20];

  if (r.vbus < 0.5f) snprintf(val[0], sizeof(val[0]), "0.00V");
  else               snprintf(val[0], sizeof(val[0]), "%.2fV", r.vbus);

  if (r.sN == LN_OPEN)     snprintf(val[1], sizeof(val[1]), "OPEN");
  else if (r.shortPN)      snprintf(val[1], sizeof(val[1]), "%.2fV SHORT", r.vN);
  else if (r.rN >= 0)      snprintf(val[1], sizeof(val[1]), "%.2fV %s", r.vN, rbN);
  else                     snprintf(val[1], sizeof(val[1]), "%.2fV", r.vN);

  if (r.sP == LN_OPEN)     snprintf(val[2], sizeof(val[2]), "OPEN");
  else if (r.shortPN)      snprintf(val[2], sizeof(val[2]), "%.2fV SHORT", r.vP);
  else if (r.rP >= 0)      snprintf(val[2], sizeof(val[2]), "%.2fV %s", r.vP, rbP);
  else                     snprintf(val[2], sizeof(val[2]), "%.2fV", r.vP);

  snprintf(val[3], sizeof(val[3]), "USB ТЕСТЕР");

  const int scaleL = 3, scaleV = 2;
  const int boxX = 2, boxW = 80;
  const int ry[4] = {2, 34, 66, 98};
  // The rotated view lists GND first, the plain view lists VBUS first.
  static const int orderRot[4]  = {3, 2, 1, 0};
  static const int orderFlat[4] = {0, 1, 2, 3};
  const int *ord = glcd_flip ? orderRot : orderFlat;

  int idxDm = -1, idxDp = -1, idxGnd = -1;
  for (int i = 0; i < 4; ++i) {
    if (ord[i] == 1) idxDm = i;
    if (ord[i] == 2) idxDp = i;
    if (ord[i] == 3) idxGnd = i;
  }

  for (int i = 0; i < 4; ++i) {
    const int k = ord[i], yy = ry[i];
    rect(boxX, yy - 2, boxW, 25);
    const int tw = textChars(label[k]) * 6 * scaleL;
    drawText(boxX + (boxW - tw) / 2, yy, label[k], scaleL);
    drawTextCenter(169, yy + 4, val[k], scaleV);
  }

  if (r.shortPN && idxDm >= 0 && idxDp >= 0) {
    drawVArrow(244, ry[idxDm] + 10, ry[idxDp] + 10);
  } else {
    if (r.sP == LN_SHORT_GND && idxDp >= 0 && idxGnd >= 0)
      drawVArrow(244, ry[idxDp] + 10, ry[idxGnd] + 10);
    if (r.sN == LN_SHORT_GND && idxDm >= 0 && idxGnd >= 0)
      drawVArrow(236, ry[idxDm] + 10, ry[idxGnd] + 10);
  }
}

// ============================================================
//  Init tester: passive boot milestones
// ============================================================
static uint32_t it_t0    = 0;   // first enumeration
static uint32_t it_led   = 0;   // first LED state from the host
static uint32_t it_os    = 0;   // protocol handover or re-enumeration
static bool     it_os_seen = false;
static bool     it_saw_boot = false;
static bool     it_beeped   = false;

static void init_test_reset() {
  it_t0 = it_led = it_os = 0;
  led_reports = 0;
  led_state = 0;
  it_os_seen = false;
  it_saw_boot = false;
  it_beeped = false;
  if (TinyUSBDevice.mounted()) it_t0 = millis();
}

static void fmt_time(char *b, size_t n, uint32_t mark) {
  if (mark == 0 || it_t0 == 0 || mark < it_t0) { snprintf(b, n, "--"); return; }
  snprintf(b, n, "%.1fS", (mark - it_t0) / 1000.0f);
}

static void render_init() {
  memset(glcd_fb, 0xFF, sizeof(glcd_fb));

  drawTextCenter(GLCD_W / 2, 2, "ТЕСТЕР ИНИЦИАЛИЗАЦИИ ПК", 1);

  // The OS is detected by whichever host signal shows up first.
  uint32_t t_load = 0;
  if (it_os && it_led) t_load = (it_os < it_led) ? it_os : it_led;
  else                 t_load = it_os ? it_os : it_led;

  char v1[20], v2[20];
  snprintf(v1, sizeof(v1), "%s", (it_t0 != 0) ? "YES" : "NO");
  fmt_time(v2, sizeof(v2), t_load);

  static const char *const label[2] = {"INIT", "OS BOOT"};
  const char *val[2] = {v1, v2};
  const int boxY[2] = {12, 66};

  for (int i = 0; i < 2; ++i) {
    rect(2, boxY[i], 252, 48);
    drawText(8, boxY[i] + 16, label[i], 2);
    drawTextRight(250, boxY[i] + 16, val[i], 2);
  }
}

// ============================================================
//  Sketch
// ============================================================
static Mode     g_mode   = MODE_PORT;
static bool     g_manual = false;   // the user has chosen a mode by hand

// 0 = nothing, 1 = short press, 2 = long press. BOOTSEL reads the flash CS
// pad, so only sample it on demand.
static uint8_t button_event() {
  static bool     down = false;
  static uint32_t tDown = 0;
  static bool     longSent = false;
  static uint32_t lastSample = 0;

  const uint32_t ms = millis();
  // Reading BOOTSEL floats the flash chip select and disables interrupts for
  // a moment, so sample it at 50 Hz and not in a tight spin.
  if ((uint32_t)(ms - lastSample) < 20) return 0;
  lastSample = ms;

  const bool now = BOOTSEL;
  uint8_t ev = 0;

  if (now && !down) {
    down = true;
    tDown = millis();
    longSent = false;
  } else if (now && down && !longSent &&
             (uint32_t)(millis() - tDown) >= PRESS_LONG_MS) {
    longSent = true;
    ev = 2;
  } else if (!now && down) {
    down = false;
    if (!longSent && (uint32_t)(millis() - tDown) >= 40) ev = 1;   // ignore bounce
  }
  return ev;
}

static void switch_mode() {
  g_mode = (g_mode == MODE_PORT) ? MODE_INIT : MODE_PORT;
  g_manual = true;
  if (g_mode == MODE_INIT) init_test_reset();
  else                     buzzer_beep(1, 80);
  Serial.printf("mode: %s (manual until replug)\n",
                (g_mode == MODE_INIT) ? "init tester" : "port tester");
}
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
void loop() {
  const uint32_t now = millis();

  // ---- follow the host, forever ----
  // An enumerated host means we are on a computer, so this is the init tester.
  // No host at all means a charger, so this is the port tester. The check runs
  // on every pass and never gives up: a machine that only brings its USB up
  // after several minutes is still caught, and the timeline starts at that
  // moment. Replugging clears any manual choice.
  static bool prevMounted = false;
  const bool mounted = TinyUSBDevice.mounted();
  if (mounted != prevMounted) {
    g_manual = false;
    if (mounted) {
      if (it_t0 == 0) {
        it_t0 = now;
        if (!it_beeped) { it_beeped = true; beep_joy(); }
        Serial.println("INIT   enumerated");
      } else if (!it_os_seen) {
        it_os_seen = true;
        it_os = now;
        Serial.printf("OS     re-enumerated   %.1f s\n", (it_os - it_t0) / 1000.0f);
      }
    }
    prevMounted = mounted;
  }

  const Mode autoMode = mounted ? MODE_INIT : MODE_PORT;
  if (!g_manual && g_mode != autoMode) {
    g_mode = autoMode;
    Serial.printf("mode: %s (auto)\n",
                  (g_mode == MODE_INIT) ? "init tester" : "port tester");
  }

  // ---- host-driven milestones, no key presses anywhere ----
  if (it_t0 != 0 && it_led == 0 && led_reports > 0) {
    it_led = now;
    Serial.printf("LED    host set lamps  %.1f s\n", (it_led - it_t0) / 1000.0f);
  }

  const bool reportProto = (usb_hid.getProtocol() == HID_PROTOCOL_REPORT);
  if (!reportProto) it_saw_boot = true;
  if (it_saw_boot && reportProto && it_t0 != 0 && !it_os_seen) {
    it_os_seen = true;
    it_os = now;
    Serial.printf("OS     report protocol %.1f s\n", (it_os - it_t0) / 1000.0f);
  }

  // ---- one button, two gestures ----
  const uint8_t ev = button_event();
  if (ev == 2) {
    switch_mode();
  } else if (ev == 1) {
    if (g_mode == MODE_PORT) {
      glcd_flip = !glcd_flip;                     // turn the picture around
      Serial.printf("flip=%d\n", glcd_flip ? 1 : 0);
    } else {
      init_test_reset();                          // start the measurement over
      Serial.println("init measurement restarted");
    }
  }

  if (g_mode == MODE_PORT) {
    // ---- port tester ----
    static uint32_t tDraw = 0;
    if ((uint32_t)(now - tDraw) >= DRAW_MS) {
      tDraw = now;
      const Reading r = measure_port();
      render_port(r);
      lcd_send_frame(glcd_fb);
      buzzer_alarm(r.shortPN || r.sP == LN_SHORT_GND || r.sN == LN_SHORT_GND ||
                   both_lines_high(r));
      static uint8_t tick = 0;
      if (++tick >= 5) { tick = 0; print_reading(r); }
    }
  } else {
    // ---- init tester: only the screen here, milestones are handled above ----
    static uint32_t tDraw = 0;
    if ((uint32_t)(now - tDraw) >= DRAW_MS) {
      tDraw = now;
      render_init();
      lcd_send_frame(glcd_fb);
    }
  }

  static uint32_t tLog = 0;
  if ((uint32_t)(now - tLog) >= LOG_MS) {
    tLog = now;
    Serial.printf("mode=%s host=%s proto=%s led=%s reports=%lu\n",
                  (g_mode == MODE_INIT) ? "init" : "port",
                  TinyUSBDevice.mounted() ? "up" : "down",
                  (usb_hid.getProtocol() == HID_PROTOCOL_REPORT) ? "report" : "boot",
                  (led_state & KEYBOARD_LED_NUMLOCK) ? "numlock-on" : "numlock-off",
                  (unsigned long)led_reports);
  }
}

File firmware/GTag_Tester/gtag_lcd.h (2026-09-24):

// ============================================================
//  gtag_lcd.h - G-Tag 256x128 LCD driver, 4-wire transport + 5x7 font
//
//  Shared by the G-Tag tools. Transport verified word for word against a
//  logic-analyzer capture of the stock firmware (see the
//  lukdut/gtag-nrf-display project, docs/lcd-protocol-review.md).
//
//  Default wiring, change the four defines below if you moved the wires:
//    DIO=GP11  CLK=GP10  CS=GP9  RESET=GP8
//  DisplayCLK (~28.8 kHz) is supplied by the tag board and is not driven here.
//
//  Framebuffer: byte index y*32 + x/8, bit x%8, 1 = white.
// ============================================================
#pragma once
#include <Arduino.h>

#define LCD_PIN_DIO     11
#define LCD_PIN_CLK     10
#define LCD_PIN_CS       9
#define LCD_PIN_RESET    8

static constexpr uint16_t GLCD_W       = 256;
static constexpr uint16_t GLCD_H       = 128;
static constexpr uint16_t GLCD_FB_SIZE = GLCD_W * GLCD_H / 8;   // 4096
static constexpr uint8_t  GLCD_HALF_US = 2;
static constexpr bool     GLCD_INK     = false;   // black ink on white paper

static uint8_t glcd_fb[GLCD_FB_SIZE];
static bool    glcd_flip = true;                  // rotate the picture 180

// ---------------- drawing ----------------
static inline void px(int x, int y, bool white = GLCD_INK) {
  if ((unsigned)x >= (unsigned)GLCD_W || (unsigned)y >= (unsigned)GLCD_H) return;
  const int px_ = glcd_flip ? (GLCD_W - 1 - x) : x;
  const int py_ = glcd_flip ? (GLCD_H - 1 - y) : y;
  const uint16_t idx = (uint16_t)py_ * 32u + (uint16_t)(px_ >> 3);
  const uint8_t  mask = uint8_t(1u << (px_ & 7));
  if (white) glcd_fb[idx] |=  mask;
  else       glcd_fb[idx] &= uint8_t(~mask);
}

static void fillRect(int x, int y, int w, int h, bool white = GLCD_INK) {
  for (int yy = 0; yy < h; ++yy)
    for (int xx = 0; xx < w; ++xx) px(x + xx, y + yy, white);
}

static void rect(int x, int y, int w, int h, bool white = GLCD_INK) {
  for (int i = 0; i < w; ++i) { px(x + i, y, white); px(x + i, y + h - 1, white); }
  for (int i = 0; i < h; ++i) { px(x, y + i, white); px(x + w - 1, y + i, white); }
}

// Double headed vertical arrow, used to show which rows are shorted.
static void drawVArrow(int x, int y1, int y2) {
  const int top = (y1 < y2) ? y1 : y2;
  const int bot = (y1 < y2) ? y2 : y1;
  for (int y = top; y <= bot; ++y) px(x, y, GLCD_INK);
  for (int d = 0; d < 7; ++d) {
    px(x - d, top + d, GLCD_INK);
    px(x + d, top + d, GLCD_INK);
    px(x - d, bot - d, GLCD_INK);
    px(x + d, bot - d, GLCD_INK);
  }
}

// ---------------- font ----------------
// 5x7, five columns per glyph, bit 0 = top row. Latin A-Z, digits,
// punctuation and Russian Cyrillic.
static const uint8_t *glyph(uint32_t cp) {
  static const uint8_t SP[5]    = {0x00,0x00,0x00,0x00,0x00};
  static const uint8_t DOT[5]   = {0x00,0x00,0x60,0x00,0x00};
  static const uint8_t DASH[5]  = {0x08,0x08,0x08,0x08,0x08};
  static const uint8_t PLUS[5]  = {0x08,0x08,0x3E,0x08,0x08};
  static const uint8_t COL[5]   = {0x00,0x36,0x36,0x00,0x00};
  static const uint8_t SL[5]    = {0x20,0x10,0x08,0x04,0x02};
  static const uint8_t PCT[5]   = {0x23,0x13,0x08,0x64,0x62};
  /* Latin */
  static const uint8_t A[5]     = {0x7E,0x11,0x11,0x11,0x7E};
  static const uint8_t B[5]     = {0x7F,0x49,0x49,0x49,0x36};
  static const uint8_t C[5]     = {0x3E,0x41,0x41,0x41,0x22};
  static const uint8_t D[5]     = {0x7F,0x41,0x41,0x22,0x1C};
  static const uint8_t E[5]     = {0x7F,0x49,0x49,0x49,0x41};
  static const uint8_t F[5]     = {0x7F,0x09,0x09,0x09,0x01};
  static const uint8_t G[5]     = {0x3E,0x41,0x49,0x49,0x7A};
  static const uint8_t H[5]     = {0x7F,0x08,0x08,0x08,0x7F};
  static const uint8_t I[5]     = {0x00,0x41,0x7F,0x41,0x00};
  static const uint8_t J[5]     = {0x38,0x40,0x41,0x3F,0x01};
  static const uint8_t K[5]     = {0x7F,0x08,0x14,0x22,0x41};
  static const uint8_t L[5]     = {0x7F,0x40,0x40,0x40,0x40};
  static const uint8_t M[5]     = {0x7F,0x02,0x0C,0x02,0x7F};
  static const uint8_t N[5]     = {0x7F,0x02,0x0C,0x10,0x7F};
  static const uint8_t O[5]     = {0x3E,0x41,0x41,0x41,0x3E};
  static const uint8_t P[5]     = {0x7F,0x09,0x09,0x09,0x06};
  static const uint8_t Q[5]     = {0x3E,0x41,0x51,0x21,0x5E};
  static const uint8_t R[5]     = {0x7F,0x09,0x19,0x29,0x46};
  static const uint8_t S[5]     = {0x46,0x49,0x49,0x49,0x31};
  static const uint8_t T[5]     = {0x01,0x01,0x7F,0x01,0x01};
  static const uint8_t U[5]     = {0x3F,0x40,0x40,0x40,0x3F};
  static const uint8_t V[5]     = {0x1F,0x20,0x40,0x20,0x1F};
  static const uint8_t W[5]     = {0x3F,0x40,0x38,0x40,0x3F};
  static const uint8_t X[5]     = {0x63,0x14,0x08,0x14,0x63};
  static const uint8_t Y[5]     = {0x07,0x08,0x70,0x08,0x07};
  static const uint8_t Z[5]     = {0x61,0x51,0x49,0x45,0x43};
  /* Cyrillic letters without a Latin twin */
  static const uint8_t CY_B[5]  = {0x7F,0x49,0x49,0x49,0x30};
  static const uint8_t CY_G[5]  = {0x7F,0x01,0x01,0x01,0x01};
  static const uint8_t CY_D[5]  = {0x70,0x1F,0x11,0x1F,0x70};
  static const uint8_t CY_ZH[5] = {0x63,0x14,0x7F,0x14,0x63};
  static const uint8_t CY_Z[5]  = {0x41,0x49,0x49,0x49,0x3E};
  static const uint8_t CY_I[5]  = {0x7F,0x10,0x08,0x04,0x7F};  // И (diagonal rises)
  static const uint8_t CY_L[5]  = {0x7E,0x07,0x01,0x01,0x7F};
  static const uint8_t CY_P[5]  = {0x7F,0x01,0x01,0x01,0x7F};
  static const uint8_t CY_U[5]  = {0x03,0x04,0x08,0x10,0x7F};  // У (stem on the right)
  static const uint8_t CY_F[5]  = {0x3E,0x41,0x7F,0x41,0x3E};
  static const uint8_t CY_TS[5] = {0x3F,0x20,0x20,0x60,0x3F};
  static const uint8_t CY_CH[5] = {0x0F,0x08,0x08,0x08,0x7F};
  static const uint8_t CY_SH[5] = {0x7F,0x40,0x7F,0x40,0x7F};
  static const uint8_t CY_SC[5] = {0x3F,0x20,0x3F,0x60,0x3F};
  static const uint8_t CY_HRD[5]= {0x01,0x01,0x7F,0x49,0x30};
  static const uint8_t CY_Y[5]  = {0x7F,0x48,0x48,0x7F,0x30};
  static const uint8_t CY_SFT[5]= {0x7F,0x48,0x48,0x48,0x30};
  static const uint8_t CY_E[5]  = {0x3E,0x41,0x41,0x49,0x08};
  static const uint8_t CY_YU[5] = {0x7F,0x08,0x7F,0x41,0x3E};
  static const uint8_t CY_YA[5] = {0x46,0x29,0x19,0x09,0x7F};  // Я (single right wall)
  static const uint8_t G_0[5]   = {0x3E,0x51,0x49,0x45,0x3E};
  static const uint8_t G_1[5]   = {0x00,0x42,0x7F,0x40,0x00};
  static const uint8_t G_2[5]   = {0x42,0x61,0x51,0x49,0x46};
  static const uint8_t G_3[5]   = {0x21,0x41,0x45,0x4B,0x31};
  static const uint8_t G_4[5]   = {0x18,0x14,0x12,0x7F,0x10};
  static const uint8_t G_5[5]   = {0x27,0x45,0x45,0x45,0x39};
  static const uint8_t G_6[5]   = {0x3C,0x4A,0x49,0x49,0x30};
  static const uint8_t G_7[5]   = {0x01,0x71,0x09,0x05,0x03};
  static const uint8_t G_8[5]   = {0x36,0x49,0x49,0x49,0x36};
  static const uint8_t G_9[5]   = {0x06,0x49,0x49,0x29,0x1E};
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
